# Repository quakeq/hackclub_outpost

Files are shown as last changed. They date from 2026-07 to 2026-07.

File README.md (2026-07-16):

# Stickify
Our project captures the position of a person's head, arm, hands, legs, and foot through OpenCV. 
The detected position is sent to the 16*16 LED matrix to display as a stick figure. 
This project originally was intended to work in tandem with a 3D volumetric display, but due to time constraints, it is currently implemented on a 2D LED Matrix. 
Demo
## Capturing
We host a local network with a laptop's hotspot, and data is sent to, processed by, and sent out by the host laptop. We created an android app that sends live video data to the host laptop. In the laptop, the data is then processed using OpenCV to track the position of each limb of a person. The system includes wireless access from multiple devices. This is to support future expansion into capturing and displaying 3D data captured across devices. 
Network
## Display
The display is a 16x16 LED matrix that is a linkage of 4 8x8 LED Matricies. The power is daisy chained, but each LED panel has a dedicated GPIO output from the ESP32 S3. 
Circle
## Volumetric Display
Work in progress
## BOM
| material | qty |
|---|---|
| 8x8 P10 LED Matrix | 4x |
| NEMA 17 Stepper Motor | 1x |
| ESP 32 S3 | 1x |
| Raspberry Pi Pico | 1x |
| A4988 | 1x |
| USB C PD | x2 |

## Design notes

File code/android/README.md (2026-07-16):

# Cameras!  

I basically yoinked this from Google's Mediapipe examples and after testing that app on my phone and finding it worked good enough, I then made it send its data over wifi to the laptop with a Cursor agent. AI was used a lot since I have 0 experience with Android development and producing it in under 3 days would be challenging. 

## Why tf we use phones

Going into the hackathon we thought we had cameras. We didn't. Thus, we had to pivot into using android phones since Thomas noticed a library that was popular on normal cameras worked on Android.

## How to use

Phones are **sensors only**: capture camera frames, run MediaPipe Pose on-device,
and stream landmarks (not video) to the laptop over the dedicated ELLO Wi‑Fi.

Default destination:

- UDP: `192.168.50.1:9000`
- WebSocket (prototype): `ws://192.168.50.1:9001`

Phone static IPs (router config, not this app): `.11` / `.12` / `.13`.

### Build

Open this directory in Android Studio, sync Gradle, then run a flavor, e.g.
`phoneADebug`, on a physical device.

```bash
./gradlew :app:assemblePhoneADebug
```

Capture is pinned to **320×240 @ 15 FPS**, lite model, GPU delegate.

### Models

Models are downloaded into `app/src/main/assets` by `download_tasks.gradle`.

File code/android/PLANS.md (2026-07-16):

OUTPOST PLAN — PHONES
=====================
Part of: Multi-phone MediaPipe pose → Laptop relative 2D → Rotating volumetric display

ROLE
----

Phones are sensors only. Each phone:
- Captures camera frames
- Runs MediaPipe Pose on-device
- Streams landmarks only (not video) to the laptop

Do not stream MJPEG/H.264 to the laptop and run MediaPipe there. That adds encode/decode
delay and saturates the link for no gain when phones can already run inference.

ARCHITECTURE POSITION
---------------------

Phone A ──┐
Phone B ──┼── Wi‑Fi (dedicated AP) ──► Laptop
Phone C ──┘         landmarks only

MEDIAPIPE / CAPTURE
-------------------

Prefer native MediaPipe Tasks (Android Kotlin / iOS Swift), not browser MediaPipe, if
you care about latency and frame pacing.

Pin MediaPipe to a fixed input size / FPS (e.g. 640-wide, 30 FPS) so timing is stable
across all three phones.

Per frame, send roughly:
- camera_id
- frame_id / sequence number
- t_capture (monotonic or NTP-synced time)
- 33 landmarks × (x, y, z, visibility) (and world landmarks if you use them)
- optional: image size / FOV for later calibration

Payload is typically < 2 KB/frame. At 30 FPS × 3 phones that is trivial bandwidth.

NETWORK CONNECTION
------------------

Phones join the dedicated LAN (SSID: POSE-LAN) and send UDP packets to the laptop.

| Phone | IP | Send to |
|---|---|---|
| phone_a | 192.168.50.11 | 192.168.50.1:9000 |
| phone_b | 192.168.50.12 | 192.168.50.1:9000 |
| phone_c | 192.168.50.13 | 192.168.50.1:9000 |

Use static IPs. DHCP is fine for prototyping, but static avoids address changes breaking
your sender apps.

Protocol: UDP datagrams with seq + timestamp. Fire-and-forget — do not wait for ACK.

| Approach | Latency | Fit |
|---|---|---|
| UDP + seq + timestamp  | Best | Best for live landmarks  |
| WebSocket / TCP binary | Good | Simplest reliable path |
| MQTT | Worse | Avoid for pose live path |
| Cloud relays | Worst | Avoid entirely |

Encode with FlatBuffers or protobuf for production. JSON is fine for prototyping.

PACKET FORMAT
-------------

Prototype JSON:
{
  "camera_id": "phone_a",
  "seq": 1284,
  "t_capture_ms": 1739473821,
  "image_w": 1280,
  "image_h": 720,
  "landmarks": [
    {"i": 0, "x": 0.51, "y": 0.42, "z": -0.03, "v": 0.98}
  ]
}

Production binary:
- camera_id (1 byte)
- seq (uint32)
- timestamp (uint64)
- num_landmarks (uint8)
- 33 × (x, y, z, visibility) as float32

SENDER LOGIC
------------

Each phone app should:
1. Run MediaPipe Pose on the camera frame.
2. Grab landmarks immediately after inference.
3. Stamp t_capture_ms.
4. Increment seq.
5. Send one UDP packet to 192.168.50.1:9000.

Android/Kotlin sketch:

val json = """
{
  "camera_id":"phone_a",
  "seq":$seq,
  "t_capture_ms":$timestamp,
  "landmarks":$landmarksJson
}
""".trimIndent()

val bytes = json.toByteArray()
socket.send(DatagramPacket(bytes, bytes.size, InetAddress.getByName("192.168.50.1"), 9000))

TIME SYNC
---------

Each pose packet must include a capture timestamp.

- Sync phone clocks to laptop over SNTP if possible 
- Even if phone clocks are not perfect, relative sync within ~10–30 ms is often enough
  if the laptop buffers 1–2 frames for alignment

WI‑FI TIPS
----------

- Use 5 GHz, not 2.4 GHz
- Keep phones close to AP
- Fixed Wi‑Fi channel, not auto
- No other heavy traffic on that SSID
- Disable phone battery optimizations for your sender app
- Keep screen on / plugged in during capture
- Use identical capture resolution/FPS on all phones

PROTOTYPE PATH
--------------

1. One phone → WebSocket JSON → laptop (print FPS/latency)
2. Switch to UDP binary
3. Add second and third phones
4. Confirm 20–30 FPS stable on all three before laptop relative-2D work begins

WHAT TO AVOID
-------------

- Streaming video "just in case"
- Routing through the public internet or a phone hotspot daisy-chain
- Sending without timestamps (laptop needs them for multi-camera sync)
- Variable capture resolution/FPS across phones

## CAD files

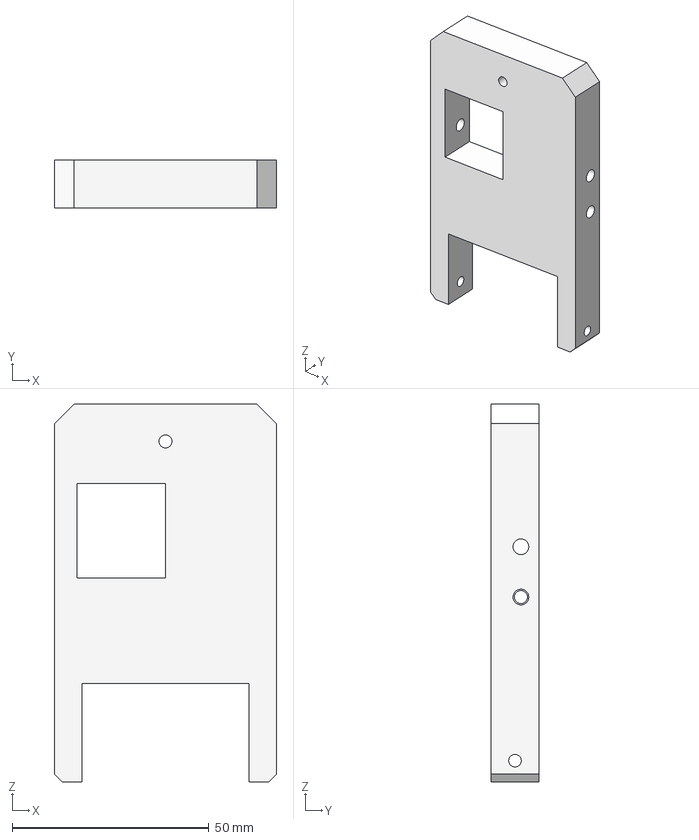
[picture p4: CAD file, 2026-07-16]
pivot-top-mount.step
56.4 x 12.1 x 96.0 mm

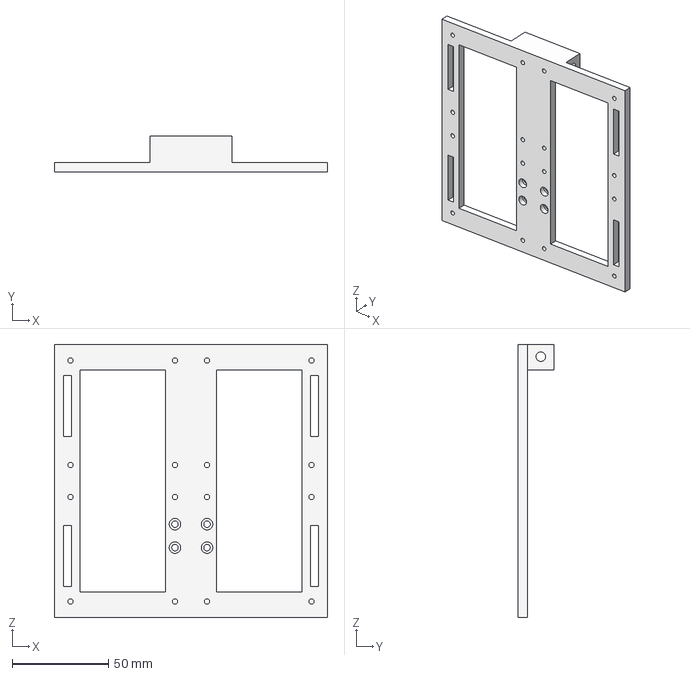
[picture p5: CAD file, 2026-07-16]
led-frame-final.step
142.0 x 18.9 x 142.0 mm

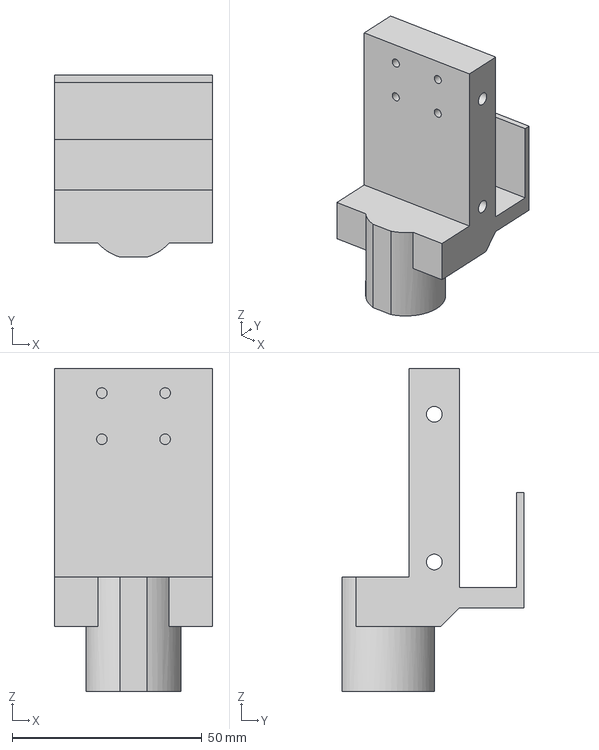
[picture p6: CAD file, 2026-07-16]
motor-mount-final.step
41.8 x 48.1 x 85.2 mm

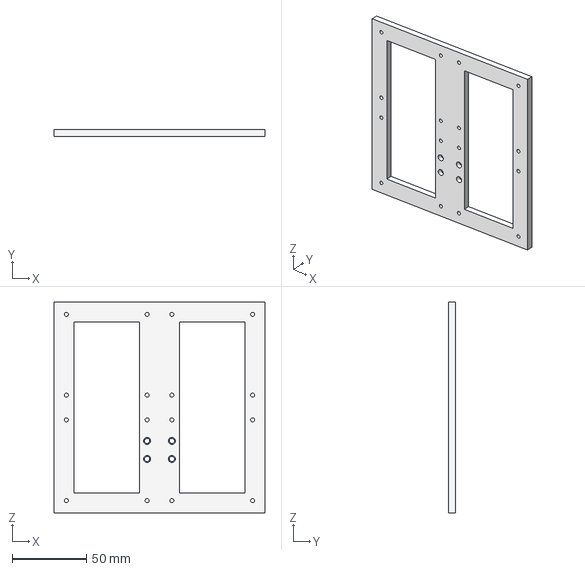
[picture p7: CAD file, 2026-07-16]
led-frame.step
142.0 x 5.00 x 142.0 mm

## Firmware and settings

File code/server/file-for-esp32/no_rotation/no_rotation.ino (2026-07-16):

/*
 * Outpost ESP32 volumetric display
 * --------------------------------
 * Board: ESP32S3 Dev Module, USB CDC On Boot = Enabled
 * Library: FastLED
 *
 * Laptop protocol (see outpost sender.py / PLAN.md):
 *   UDP JSON to 192.168.50.20:9100 on POSE-LAN
 *
 *   {"frame_id":1842,"t_capture_ms":...,"angle":137.25,
 *    "targets":[
 *      {"part":"head","x":0.5,"y":0.2,"z":-0.1},
 *      {"part":"left_hand","x":0.2,"y":0.4,"z":0.0},
 *      {"part":"right_hand","x":0.8,"y":0.4,"z":0.0},
 *      {"part":"left_foot","x":0.4,"y":0.9,"z":0.1},
 *      {"part":"right_foot","x":0.6,"y":0.9,"z":0.1}]}
 *   {"type":"heartbeat","t_send_ms":...}
 *
 * `angle` is the current shaft angle in degrees [0, 360).
 * The five targets are the head, wrists, and ankles in MediaPipe coordinates.
 * The diameter-mounted panel paints a static cylinder plus targets intersecting
 * its current slice. Only the five targets are animated.
 *
 * Four independent 8x8 WS2812B panels arranged:
 *   [GPIO4][GPIO5]
 *   [GPIO6][GPIO7]
 *
 * Use a stout 5 V supply; common its GND with ESP32 GND. Do not power 256
 * LEDs from USB or the ESP32's 5 V pin.
 */

 #include <Arduino.h>
 #include <FastLED.h>
 #include <WiFi.h>
 #include <WiFiUdp.h>
 #include <math.h>
 #include <string.h>
 #include <stdlib.h>
 
 // --- Wi-Fi and UDP ---
 static const char *WIFI_SSID = "ELLO";
 static const char *WIFI_PASS = "ellothomas995!";  // change to your AP password
 static const uint8_t WIFI_IP[4] = {192, 168, 50, 20};
 static const uint8_t WIFI_GW[4] = {192, 168, 50, 1};
 static const uint8_t WIFI_MASK[4] = {255, 255, 255, 0};
 static const uint16_t UDP_PORT = 9100;
 static const uint32_t RX_TIMEOUT_MS = 1000;
 
 // --- Four 8x8 panels forming one 16x16 display ---
 #define PANEL 64
 #define STRIPS 4
 #define TOTAL (PANEL * STRIPS)
 #define PANEL_W 16
 #define PANEL_H 16
 #define PANEL_PIXELS TOTAL
 
 // Set true if the chase on each individual panel zigzags row to row.
 static const bool SERPENTINE = false;
 static const uint8_t LED_BRIGHTNESS = 40;
 static const uint16_t LED_POWER_MA = 2000;
 
 // Pose target mapping and rotating-slice thickness, in LED-pitch units.
 static const float TARGET_X_SCALE = 10.0f;
 static const float TARGET_Z_SCALE = 10.0f;
 static const float TARGET_SLICE_HALF_WIDTH = 1.25f;
 
 WiFiUDP Udp;
 
 CRGB leds[TOTAL];
 static uint8_t packetBuf[1536];
 static uint8_t frameRgb[PANEL_PIXELS * 3];
 
 struct PoseTarget {
   float x;
   float y;
   float z;
 };
 
 static const uint8_t TARGET_COUNT = 5;
 static const char *TARGET_NAMES[TARGET_COUNT] = {
     "head", "left_hand", "right_hand", "left_foot", "right_foot"};
 static const uint8_t TARGET_COLORS[TARGET_COUNT][3] = {
     {255, 180, 40},
     {40, 120, 255},
     {255, 60, 120},
     {40, 255, 120},
     {180, 80, 255},
 };
 
 static int32_t lastFrameId = -1;
 static float currentAngle = 0.0f;
 static PoseTarget currentTargets[TARGET_COUNT];
 static bool havePose = false;
 static uint32_t lastRxMs = 0;
 static bool blanked = true;
 
 static uint32_t okCount = 0;
 static uint32_t badCount = 0;
 static uint32_t dupCount = 0;
 
 // Map (x,y) in the 16x16 square to the matching 8x8 panel.
 // Physical layout: [0][1]
 //                  [2][3]
 static uint16_t xy(uint8_t x, uint8_t y) {
   const uint8_t panel = (y / 8) * 2 + (x / 8);
   uint8_t px = x % 8;
   const uint8_t py = y % 8;
   if (SERPENTINE && (py & 1)) {
     px = 7 - px;
   }
   return panel * PANEL + py * 8 + px;
 }
 
 static void led_driver_clear() {
   FastLED.clear(true);
 }
 
 static void led_driver_show_rgb888(const uint8_t *rgb888) {
   for (uint8_t y = 0; y < PANEL_H; y++) {
     for (uint8_t x = 0; x < PANEL_W; x++) {
       const size_t off = ((size_t)y * PANEL_W + x) * 3;
       leds[xy(x, y)] =
           CRGB(rgb888[off], rgb888[off + 1], rgb888[off + 2]);
     }
   }
   FastLED.show();
 }
 
 static void led_driver_begin() {
  FastLED.addLeds<WS2812B, 6, GRB>(leds, 0 * PANEL, PANEL);
  FastLED.addLeds<WS2812B, 5, GRB>(leds, 1 * PANEL, PANEL);
  FastLED.addLeds<WS2812B, 4, GRB>(leds, 2 * PANEL, PANEL);
  FastLED.addLeds<WS2812B, 7, GRB>(leds, 3 * PANEL, PANEL);
   FastLED.setMaxPowerInVoltsAndMilliamps(5, LED_POWER_MA);
   FastLED.setBrightness(LED_BRIGHTNESS);
   led_driver_clear();
 }
 
 // --- tiny JSON number extractors (no ArduinoJson dependency) ---
 
 static const char *find_key(const char *json, const char *key) {
   // Match "key" then optional whitespace and ':'.
   char pattern[48];
   const size_t keyLen = strlen(key);
   if (keyLen + 3 >= sizeof(pattern)) {
     return nullptr;
   }
   pattern[0] = '"';
   memcpy(pattern + 1, key, keyLen);
   pattern[keyLen + 1] = '"';
   pattern[keyLen + 2] = '\0';
 
   const char *p = json;
   while ((p = strstr(p, pattern)) != nullptr) {
     const char *after = p + keyLen + 2;
     while (*after == ' ' || *after == '\t') {
       after++;
     }
     if (*after != ':') {
       p += keyLen + 2;
       continue;
     }
     return after + 1;
   }
   return nullptr;
 }
 
 static bool parse_number_after(const char *valueStart, double *out) {
   if (valueStart == nullptr || out == nullptr) {
     return false;
   }
   while (*valueStart == ' ' || *valueStart == '\t') {
     valueStart++;
   }
   char *end = nullptr;
   const double v = strtod(valueStart, &end);
   if (end == valueStart) {
     return false;
   }
   *out = v;
   return true;
 }
 
 static bool json_get_number(const char *json, const char *key, double *out) {
   return parse_number_after(find_key(json, key), out);
 }
 
 static bool json_is_heartbeat(const char *json) {
   const char *type = strstr(json, "\"type\"");
   if (type == nullptr) {
     return false;
   }
   return strstr(type, "heartbeat") != nullptr;
 }
 
 static bool json_get_target(const char *json, const char *part, PoseTarget *out) {
   if (out == nullptr) {
     return false;
   }
   const char *partAt = strstr(json, part);
   if (partAt == nullptr) {
     return false;
   }
   double x = 0;
   double y = 0;
   double z = 0;
   if (!json_get_number(partAt, "x", &x) ||
       !json_get_number(partAt, "y", &y) ||
       !json_get_number(partAt, "z", &z) ||
       !isfinite(x) || !isfinite(y) || !isfinite(z)) {
     return false;
   }
   out->x = (float)x;
   out->y = (float)y;
   out->z = (float)z;
   return true;
 }
 
 static float wrap360(float deg) {
   while (deg < 0.0f) {
     deg += 360.0f;
   }
   while (deg >= 360.0f) {
     deg -= 360.0f;
   }
   return deg;
 }
 
 static void set_pixel(uint8_t col, uint8_t row, uint8_t r, uint8_t g, uint8_t b) {
   const size_t off = ((size_t)row * PANEL_W + col) * 3;
   frameRgb[off] = r;
   frameRgb[off + 1] = g;
   frameRgb[off + 2] = b;
 }
 
 static void add_pixel(uint8_t col, uint8_t row, uint8_t r, uint8_t g, uint8_t b) {
   const size_t off = ((size_t)row * PANEL_W + col) * 3;
   const uint16_t nr = (uint16_t)frameRgb[off] + r;
   const uint16_t ng = (uint16_t)frameRgb[off + 1] + g;
   const uint16_t nb = (uint16_t)frameRgb[off + 2] + b;
   frameRgb[off] = nr > 255 ? 255 : (uint8_t)nr;
   frameRgb[off + 1] = ng > 255 ? 255 : (uint8_t)ng;
   frameRgb[off + 2] = nb > 255 ? 255 : (uint8_t)nb;
 }
 
 static float clampf(float value, float low, float high) {
   return value < low ? low : (value > high ? high : value);
 }
 
 static void draw_target(int col, int row, const uint8_t color[3]) {
   for (int dy = -1; dy <= 1; dy++) {
     for (int dx = -1; dx <= 1; dx++) {
       const int c = col + dx;
       const int r = row + dy;
       if (c < 0 || c >= PANEL_W || r < 0 || r >= PANEL_H) {
         continue;
       }
       const uint8_t scale = (dx == 0 && dy == 0) ? 255 : 80;
       add_pixel(
           (uint8_t)c,
           (uint8_t)r,
           (uint8_t)(((uint16_t)color[0] * scale) / 255),
           (uint8_t)(((uint16_t)color[1] * scale) / 255),
           (uint8_t)(((uint16_t)color[2] * scale) / 255));
     }
   }
 }
 
 // Plot a single pixel with bounds checking.
 static void plot(int col, int row, const uint8_t c[3]) {
   if (col < 0 || col >= PANEL_W || row < 0 || row >= PANEL_H) {
     return;
   }
   set_pixel((uint8_t)col, (uint8_t)row, c[0], c[1], c[2]);
 }
 
 // Bresenham line drawing; produces a 1-pixel wide line on the 16x16 grid.
 static void draw_line(int x0, int y0, int x1, int y1, const uint8_t c[3]) {
   int dx = abs(x1 - x0), sx = x0 < x1 ? 1 : -1;
   int dy = -abs(y1 - y0), sy = y0 < y1 ? 1 : -1;
   int err = dx + dy;
 
   for (;;) {
     plot(x0, y0, c);
     if (x0 == x1 && y0 == y1) {
       break;
     }
     const int e2 = 2 * err;
     if (e2 >= dy) {
       err += dy;
       x0 += sx;
     }
     if (e2 <= dx) {
       err += dx;
       y0 += sy;
     }
   }
 }
 
 // Draw a radius-1 ring: the 8 neighbors around (cx, cy).
 static void draw_ring1(int cx, int cy, const uint8_t c[3]) {
   plot(cx - 1, cy - 1, c);
   plot(cx, cy - 1, c);
   plot(cx + 1, cy - 1, c);
   plot(cx - 1, cy, c);
   plot(cx + 1, cy, c);
   plot(cx - 1, cy + 1, c);
   plot(cx, cy + 1, c);
   plot(cx + 1, cy + 1, c);
 }
 
 static void render_slice(float angle_deg, const PoseTarget targets[TARGET_COUNT]) {
   (void)angle_deg;  // This sketch draws the figure flat from x/y.
   memset(frameRgb, 0, sizeof(frameRgb));
 
   // Warm amber stick-figure color.
   const uint8_t c[3] = {255, 180, 40};
 
   // Project targets flat: col = x*(PANEL_W-1), row = y*(PANEL_H-1).
   const int headCol = (int)lroundf(clampf(targets[0].x, 0.0f, 1.0f) *
                                    (float)(PANEL_W - 1));
   const int headRow = (int)lroundf(clampf(targets[0].y, 0.0f, 1.0f) *
                                    (float)(PANEL_H - 1));
 
   const int leftHandCol =
       (int)lroundf(clampf(targets[1].x, 0.0f, 1.0f) * (float)(PANEL_W - 1));
   const int leftHandRow =
       (int)lroundf(clampf(targets[1].y, 0.0f, 1.0f) * (float)(PANEL_H - 1));
 
   const int rightHandCol =
       (int)lroundf(clampf(targets[2].x, 0.0f, 1.0f) * (float)(PANEL_W - 1));
   const int rightHandRow =
       (int)lroundf(clampf(targets[2].y, 0.0f, 1.0f) * (float)(PANEL_H - 1));
 
   const int leftFootCol =
       (int)lroundf(clampf(targets[3].x, 0.0f, 1.0f) * (float)(PANEL_W - 1));
   const int leftFootRow =
       (int)lroundf(clampf(targets[3].y, 0.0f, 1.0f) * (float)(PANEL_H - 1));
 
   const int rightFootCol =
       (int)lroundf(clampf(targets[4].x, 0.0f, 1.0f) * (float)(PANEL_W - 1));
   const int rightFootRow =
       (int)lroundf(clampf(targets[4].y, 0.0f, 1.0f) * (float)(PANEL_H - 1));
 
   // Waist is always 40% of the screen below the head.
   const int waistDelta = (int)lroundf(0.40f * (float)PANEL_H);
   int waistRow = headRow + waistDelta;
   if (waistRow < 0) {
     waistRow = 0;
   }
   if (waistRow >= PANEL_H) {
     waistRow = PANEL_H - 1;
   }
   const int waistCol = headCol;
 
   // Arms start 1 LED below the head.
   int shoulderRow = headRow + 1;
   if (shoulderRow < 0) {
     shoulderRow = 0;
   }
   if (shoulderRow >= PANEL_H) {
     shoulderRow = PANEL_H - 1;
   }
   const int shoulderCol = headCol;
 
   draw_ring1(headCol, headRow, c);
 
   // Spine.
   draw_line(headCol, headRow, waistCol, waistRow, c);
 
   // Legs.
   draw_line(waistCol, waistRow, leftFootCol, leftFootRow, c);
   draw_line(waistCol, waistRow, rightFootCol, rightFootRow, c);
 
   // Arms.
   draw_line(shoulderCol, shoulderRow, leftHandCol, leftHandRow, c);
   draw_line(shoulderCol, shoulderRow, rightHandCol, rightHandRow, c);
 }
 
 static void show_idle() {
   memset(frameRgb, 0, sizeof(frameRgb));
   // Dim chasing dot so a live but unfed board is obvious.
   const uint8_t col = (millis() / 80) % PANEL_W;
   const uint8_t row = PANEL_H / 2;
   set_pixel(col, row, 0, 0, 40);
   led_driver_show_rgb888(frameRgb);
 }
 
 static void apply_display() {
   render_slice(currentAngle, currentTargets);
   led_driver_show_rgb888(frameRgb);
   blanked = false;
 }
 
 static bool handle_json(const char *json) {
   if (json_is_heartbeat(json)) {
     lastRxMs = millis();
     return true;
   }
 
   double frameId = 0;
   double angle = 0;
   if (!json_get_number(json, "frame_id", &frameId) ||
       !json_get_number(json, "angle", &angle) ||
       !isfinite(frameId) || !isfinite(angle)) {
     return false;
   }
 
   PoseTarget parsedTargets[TARGET_COUNT];
   for (uint8_t i = 0; i < TARGET_COUNT; i++) {
     if (!json_get_target(json, TARGET_NAMES[i], &parsedTargets[i])) {
       return false;
     }
   }
 
   const int32_t id = (int32_t)frameId;
   if (id <= lastFrameId) {
     dupCount++;
     lastRxMs = millis();
     return true;  // well-formed but stale/duplicate
   }
 
   lastFrameId = id;
   currentAngle = wrap360((float)angle);
   memcpy(currentTargets, parsedTargets, sizeof(currentTargets));
   havePose = true;
   lastRxMs = millis();
   apply_display();
   return true;
 }
 
 static void connect_wifi() {
   WiFi.mode(WIFI_STA);
   WiFi.setSleep(false);
 
   IPAddress ip(WIFI_IP[0], WIFI_IP[1], WIFI_IP[2], WIFI_IP[3]);
   IPAddress gw(WIFI_GW[0], WIFI_GW[1], WIFI_GW[2], WIFI_GW[3]);
   IPAddress mask(WIFI_MASK[0], WIFI_MASK[1], WIFI_MASK[2], WIFI_MASK[3]);
   if (!WiFi.config(ip, gw, mask)) {
     Serial.println("WiFi.config failed");
   }
 
   Serial.print("Connecting to ");
   Serial.println(WIFI_SSID);
   WiFi.begin(WIFI_SSID, WIFI_PASS);
 
   const uint32_t start = millis();
   while (WiFi.status() != WL_CONNECTED && (millis() - start) < 20000) {
     delay(250);
     Serial.print('.');
   }
   Serial.println();
 
   if (WiFi.status() == WL_CONNECTED) {
     Serial.print("IP ");
     Serial.println(WiFi.localIP());
   } else {
     Serial.println("WiFi connect timed out — will keep retrying");
   }
 }
 
 void setup() {
   Serial.begin(115200);
   delay(200);
 
   led_driver_begin();
   show_idle();
 
   connect_wifi();
 
   Udp.begin(UDP_PORT);
   Serial.print("UDP listen :");
   Serial.println(UDP_PORT);
   Serial.println("outpost_display ready (angle + 5 targets JSON)");
 }
 
 void loop() {
   if (WiFi.status() != WL_CONNECTED) {
     static uint32_t lastAttempt = 0;
     if (millis() - lastAttempt > 3000) {
       lastAttempt = millis();
       WiFi.disconnect();
       WiFi.begin(WIFI_SSID, WIFI_PASS);
       Serial.println("WiFi reconnecting...");
     }
   }
 
   const int packetSize = Udp.parsePacket();
   if (packetSize > 0) {
     if (packetSize >= (int)sizeof(packetBuf)) {
       while (Udp.available()) {
         Udp.read();
       }
       badCount++;
     } else {
       const int len = Udp.read(packetBuf, packetSize);
       if (len > 0) {
         packetBuf[len] = 0;
         if (handle_json((const char *)packetBuf)) {
           okCount++;
         } else {
           badCount++;
         }
         if ((okCount & 0x3F) == 0) {
           Serial.print("ok=");
           Serial.print(okCount);
           Serial.print(" bad=");
           Serial.print(badCount);
           Serial.print(" dup=");
           Serial.print(dupCount);
           Serial.print(" angle=");
           Serial.println(currentAngle, 1);
         }
       }
     }
   }
 
   const uint32_t now = millis();
   if (havePose && !blanked && (now - lastRxMs) > RX_TIMEOUT_MS) {
     led_driver_clear();
     blanked = true;
     havePose = false;
     Serial.println("rx timeout — blanked");
   }
 
   if (!havePose) {
     static uint32_t lastIdle = 0;
     if (now - lastIdle > 80) {
       lastIdle = now;
       show_idle();
     }
   }
 }
 

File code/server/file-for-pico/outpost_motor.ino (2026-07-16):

/*
 * Outpost Pico stepper controller
 * -------------------------------
 * Flash with Arduino IDE + "Raspberry Pi Pico" (Earle Philhower core)
 * or equivalent Arduino-Pico toolchain. USB CDC appears as /dev/ttyACM0.
 *
 * Laptop protocol (see outpost motor.py):
 *   Host writes:  ?\n
 *   Pico replies: pos=<int> target=<int>\n
 *
 * Optional host commands:
 *   pos=<int>\n      force current position counter
 *   enable\n / disable\n
 *
 * Assumes NEMA17 @ 1/16 microstepping => 3200 microsteps / revolution.
 * Wire STEP / DIR / EN to your driver; set MICROSTEP jumpers to 1/16.
 */

#include <Arduino.h>

// --- pin map (change to match your wiring) ---
static const uint8_t PIN_STEP = 2;
static const uint8_t PIN_DIR = 3;
static const uint8_t PIN_EN = 4;  // active LOW on most A4988/DRV8825 boards

static const uint32_t STEP_PULSE_US = 4;
static const uint32_t STEPS_PER_REV = 3200;

// Speed tuning (delay between step half-cycles; lower = faster)
static const uint32_t MIN_DELAY_MICROS = 200;   // top speed
static const uint32_t MAX_DELAY_MICROS = 2000;  // startup torque
static const uint32_t ACCEL_STEP = 3;           // ramp smoothness

static int32_t position_steps = 0;
static bool motor_enabled = false;
static bool decelerating = false;
static uint32_t current_delay_micros = MAX_DELAY_MICROS;
static uint32_t last_step_us = 0;

static String line_buf;

static void set_driver_enabled(bool on) {
  digitalWrite(PIN_EN, on ? LOW : HIGH);
}

static void set_enabled(bool on) {
  if (on) {
    decelerating = false;
    current_delay_micros = MAX_DELAY_MICROS;
    last_step_us = micros();
    motor_enabled = true;
    set_driver_enabled(true);
    return;
  }
  if (motor_enabled) {
    decelerating = true;
  }
}

static void step_once() {
  digitalWrite(PIN_STEP, HIGH);
  delayMicroseconds(STEP_PULSE_US);
  digitalWrite(PIN_STEP, LOW);
  position_steps = (position_steps + 1) % STEPS_PER_REV;
}

static void service_motion() {
  if (!motor_enabled && !decelerating) {
    return;
  }

  const uint32_t now = micros();
  const uint32_t interval = current_delay_micros * 2;
  if ((uint32_t)(now - last_step_us) < interval) {
    return;
  }
  last_step_us = now;
  step_once();

  if (decelerating) {
    if (current_delay_micros < MAX_DELAY_MICROS) {
      current_delay_micros += ACCEL_STEP;
      if (current_delay_micros > MAX_DELAY_MICROS) {
        current_delay_micros = MAX_DELAY_MICROS;
      }
    } else {
      motor_enabled = false;
      decelerating = false;
      set_driver_enabled(false);
    }
    return;
  }

  if (motor_enabled && current_delay_micros > MIN_DELAY_MICROS) {
    if (current_delay_micros > MIN_DELAY_MICROS + ACCEL_STEP) {
      current_delay_micros -= ACCEL_STEP;
    } else {
      current_delay_micros = MIN_DELAY_MICROS;
    }
  }
}

static void reply_state() {
  Serial.print(F("pos="));
  Serial.print(position_steps);
  Serial.print(F(" target="));
  Serial.println(position_steps);
}

static void handle_line(String line) {
  line.trim();
  if (line.length() == 0) {
    return;
  }
  if (line.equals("?") || line.equalsIgnoreCase("status")) {
    reply_state();
    return;
  }
  if (line.equalsIgnoreCase("enable")) {
    set_enabled(true);
    reply_state();
    return;
  }
  if (line.equalsIgnoreCase("disable") || line.equalsIgnoreCase("stop")) {
    set_enabled(false);
    reply_state();
    return;
  }
  if (line.startsWith("pos=")) {
    position_steps = line.substring(4).toInt() % (int32_t)STEPS_PER_REV;
    if (position_steps < 0) {
      position_steps += STEPS_PER_REV;
    }
    reply_state();
    return;
  }
  // Unknown command: still answer in protocol shape so the laptop can recover.
  reply_state();
}

void setup() {
  pinMode(PIN_STEP, OUTPUT);
  pinMode(PIN_DIR, OUTPUT);
  pinMode(PIN_EN, OUTPUT);

  digitalWrite(PIN_STEP, LOW);
  digitalWrite(PIN_DIR, HIGH);
  set_driver_enabled(true);
  set_enabled(true);

  Serial.begin(115200);
  while (!Serial && millis() < 2000) {
    // USB CDC enumerate
  }
}

void loop() {
  while (Serial.available() > 0) {
    const char c = (char)Serial.read();
    if (c == '\n' || c == '\r') {
      if (line_buf.length() > 0) {
        handle_line(line_buf);
        line_buf = "";
      }
    } else if (line_buf.length() < 64) {
      line_buf += c;
    }
  }
  service_motion();
}

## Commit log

2026-07-16 Add stepper controller for Raspberry Pi Pico
2026-07-16 added camera and server code
